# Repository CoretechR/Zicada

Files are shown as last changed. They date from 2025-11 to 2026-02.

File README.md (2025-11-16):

# Zicada - DIY Zigbee Multisensor

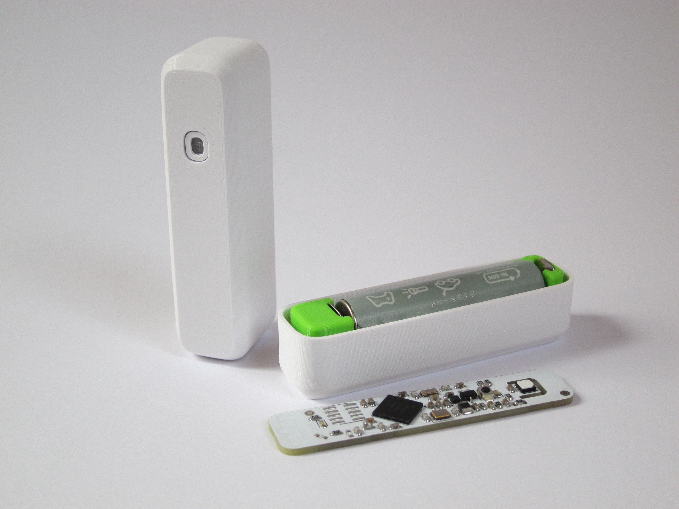
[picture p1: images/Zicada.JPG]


## Overview

Zicada is a DIY Zigbee sensor based on Nordic’s nRF52840 SoC. It combines a temperature and humidity sensor with a hall effect switch, making it suitable for both climate and door/window monitoring. Zicada is optimized for ultra-low power consumption, running at just 6µW in standby. This allows it to operate on a rechargeable AAA battery for 2 years or longer. It is fully compatible with Home Assistant (ZHA) and Zigbee2MQTT.

<div align="center">
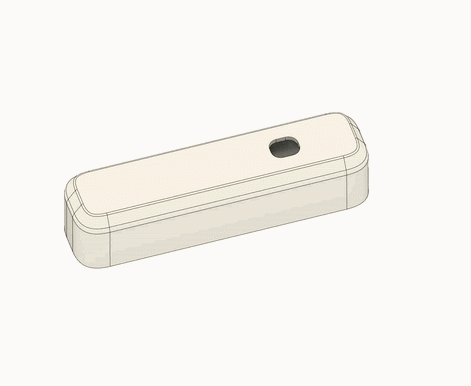
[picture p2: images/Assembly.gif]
  
</div>

### Features
* Temperature, humidity and contact sensing
* Zigbee 3.0 end device
* Compatible with Home Assistant (ZHA) and Zigbee2MQTT
* Ultra-low power consumption (6µW in Standby)
* 2+ years of battery life
* Supports AAA cells from 0.9V to 1.5V
* Small sized (62 x 15 mm) and fully 3D-printed case

### Setup Instructions

Follow these instructions to download and install the nRF Connect SDK version 2.6.0:
https://docs.nordicsemi.com/bundle/ncs-2.6.3/page/nrf/installation/install_ncs.html
Copy Zicada firmware folder into the directory ncs/projects.

When using the contact sensor with Zigbee2MQTT, copy the file "zicada_converter.js" to the directory data/external_converters/ of you Z2M install.

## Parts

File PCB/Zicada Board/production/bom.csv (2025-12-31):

Designator | Footprint | Quantity | Value | LCSC Part #
C10, C13, C14, C16, C19, C20, C21, C22, C24 | 0603 | 9 | 100nF | C1591
C11 | 0603 | 1 | 4.7uF | C1705
C12, C2 | 0603 | 2 | 1uF | C15849
C15, C17, C5, C6 | 0603 | 4 | 12pF | C107034
C18, C23 | 0603 | 2 | 10uF | C19702
C3 | 0603 | 1 | 820pF | C107057
C7 | 0603 | 1 | 0.5pF | C5137584
C8 | 0603 | 1 | 100pF | C14858
C9 | 0603 | 1 | 0.8pF | C519369
D1, D2 | 0603 | 2 | LED | C5875723
F1 | 0805 | 1 | 350mA | C207021
J2, J3 | MYOUNG MY-AAA-07 | 2 | Conn_01x01_Pin | C6937109
L1 | 0603 | 1 | 4.7nH | C1030
L2 | 1008 | 1 | 4.7uH | C280597
R1, R7 | 0603 | 2 | 0R | C116699
R2, R8 | 0603 | 2 | 330R | C105881
R4 | 0603 | 1 | 402R | C227889
R5, R6 | 0603 | 2 | 10K | C98220
SW1 | SW_SPST_B3U-1000P-B | 1 | SW_Push | C231329
U1 | Nordic_AQFN-73-1EP_7x7mm_P0.5mm | 1 | nRF52840 | C190794
U2 | Texas_PWSON-N6 | 1 | HDC2080 | C918141
U3 | SOT-23 | 1 | SM351LT | C80830
U4 | WSON-6_1.5x1.5mm_P0.5mm | 1 | TPS610981 | C470966
U5 | USON-6-1EP_2x2mm_P0.65mm_EP0.65x1.35mm | 1 | OPT3001 | C90462
Y1 | Crystal_SMD_Abracon_ABM8G-4Pin_3.2x2.5mm | 1 | 32MHz | C5552502
Y2 | Crystal_SMD_MicroCrystal_CC7V-T1A-2Pin_3.2x1.5mm | 1 | 32.768kHz | C32346

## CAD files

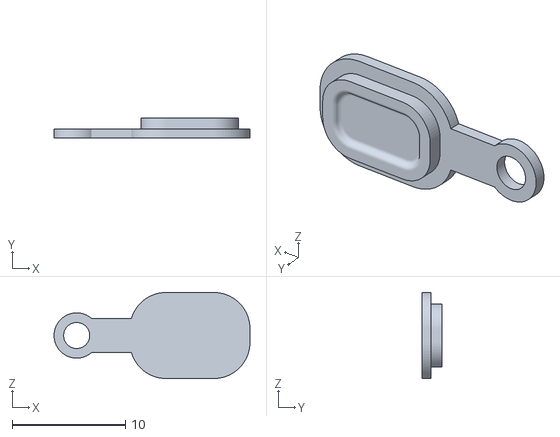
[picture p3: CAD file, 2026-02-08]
CAD/ButtonV2.stl
17.3 x 1.80 x 7.60

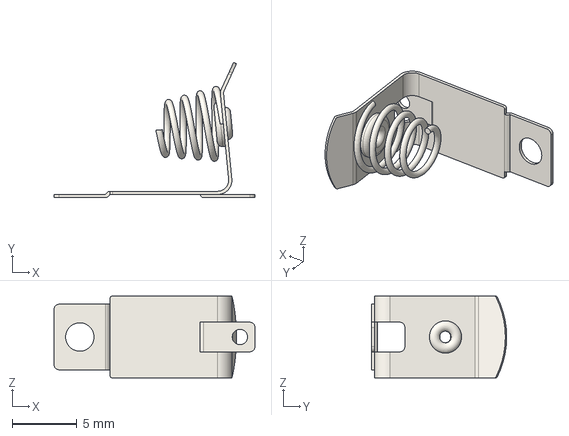
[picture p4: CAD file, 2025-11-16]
PCB/Zicada Board/project_libraries/3D-models/MY-AAA-22-J v3.step
15.6 x 10.5 x 6.35 mm

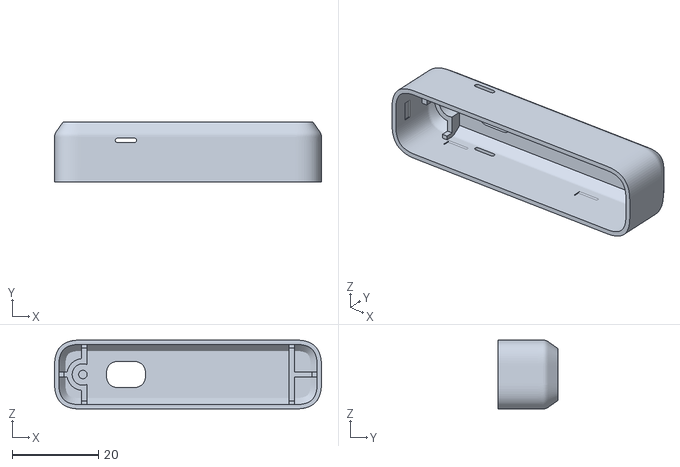
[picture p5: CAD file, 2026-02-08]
CAD/FrontV2.stl
62.0 x 14.0 x 16.0

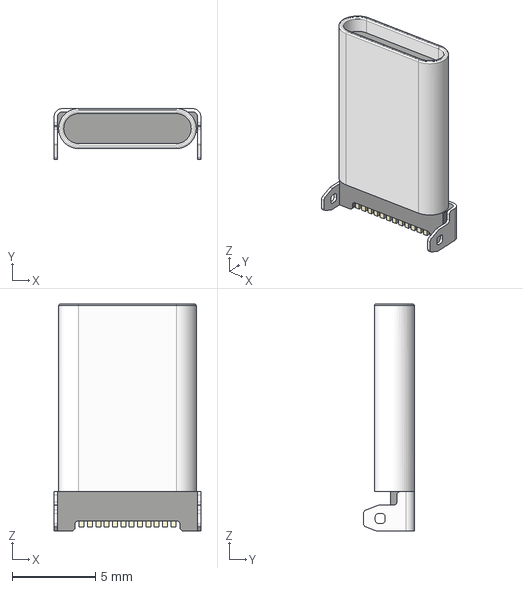
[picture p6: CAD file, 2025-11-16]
PCB/Zicada Board/project_libraries/3D-models/XKB Connection U261-121N-4BS2S v1.step
8.80 x 3.05 x 13.6 mm

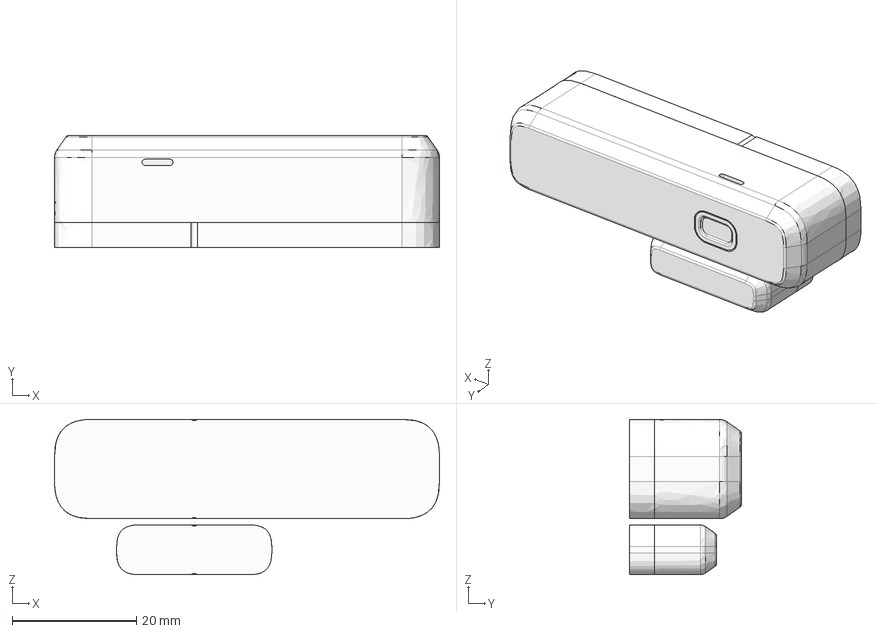
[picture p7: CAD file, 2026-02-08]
CAD/Zicada Rev2.step
62.0 x 18.0 x 25.0 mm
AAA_SIZE_BATTERY_CELL
C_0603_1608Metric x 22
L_1008_2520Metric
Crystal_SMD_Abracon_ABM8G-4Pin_3.2x2.5mm
LED_0603_1608Metric x 2
Fuse_0805_2012Metric
DFN-6-1EP_2x2mm_P0.65mm_EP1x1.6mm
R_0603_1608Metric x 7
SW_SPST_B3U-1000P-B
SOT-23
WSON-6_1.5x1.5mm_P0.5mm
L_0603_1608Metric
Texas_S-PWSON-N6
Nordic_AQFN-73-1EP_7x7mm_P0.5mm
Crystal_SMD_MicroCrystal_CC7V-T1A-2Pin_3.2x1.5mm
keystone-PN556 x 2
Zicada_pad
Zicada_PCB
Back
Button
Inlay
Magnet
MagBot
MagFront

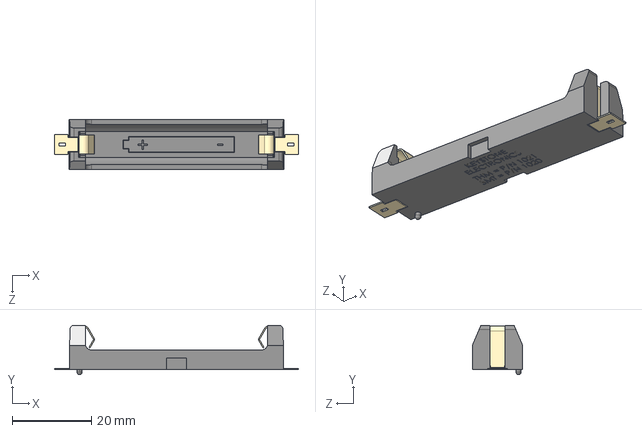
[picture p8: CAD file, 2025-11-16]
PCB/Zicada Board/project_libraries/3D-models/1020.step
61.5 x 12.4 x 12.7 mm

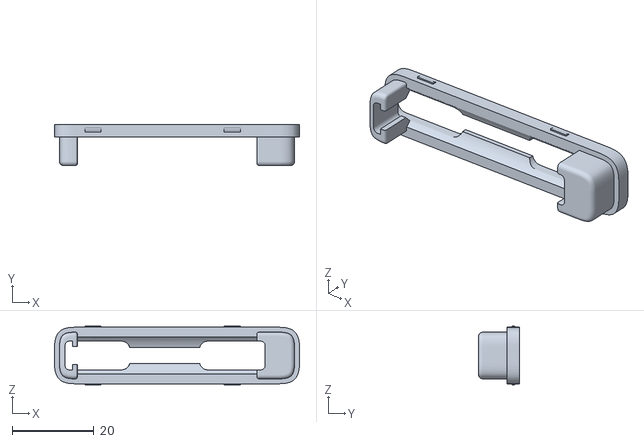
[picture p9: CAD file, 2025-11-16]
CAD/Inlay.stl
59.8 x 10.0 x 14.4

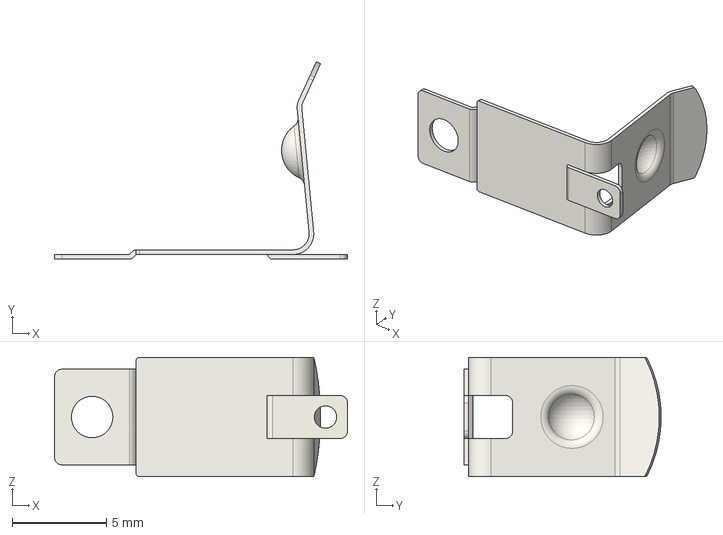
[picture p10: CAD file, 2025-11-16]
PCB/Zicada Board/project_libraries/3D-models/MY-AAA-07 v2.step
15.6 x 10.5 x 6.35 mm

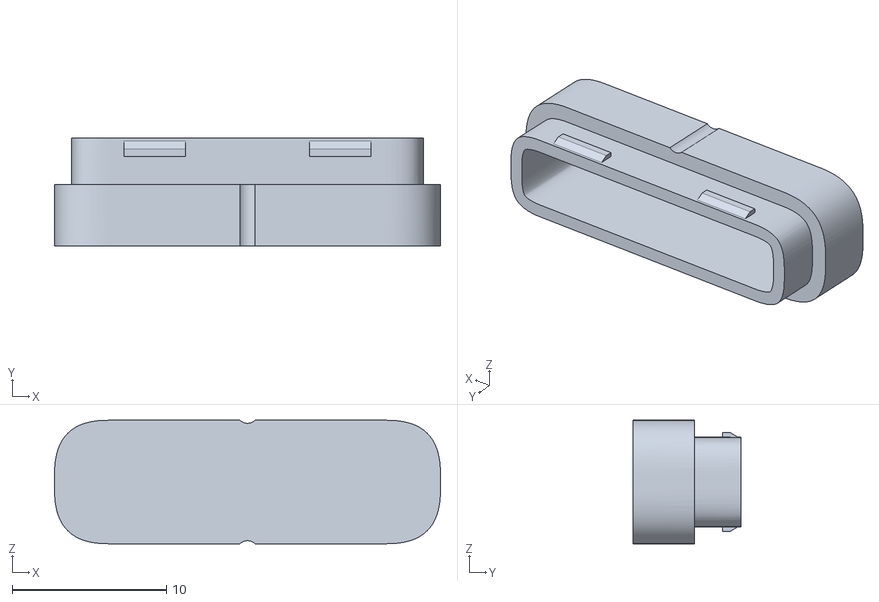
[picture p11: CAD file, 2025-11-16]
CAD/Mag Back.stl
25.0 x 7.00 x 8.00

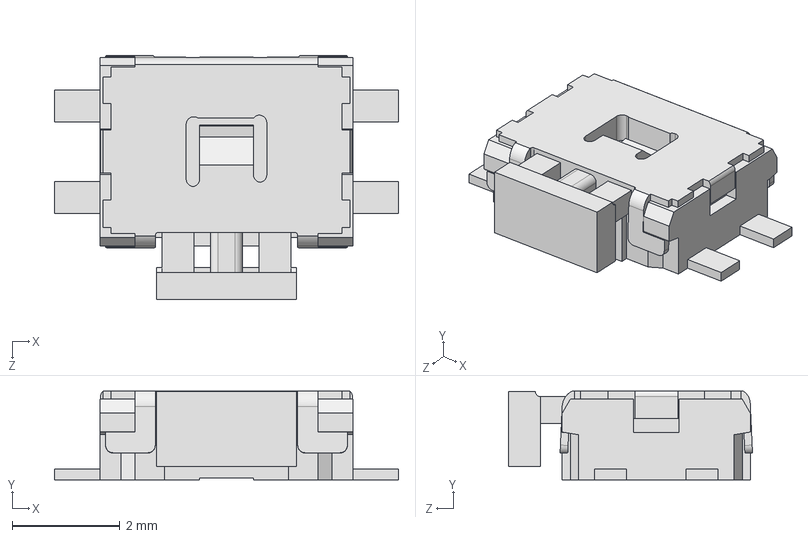
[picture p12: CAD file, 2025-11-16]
PCB/Zicada Board/project_libraries/3D-models/EVQPU-JA-02K.STEP
6.40 x 1.65 x 4.54 mm

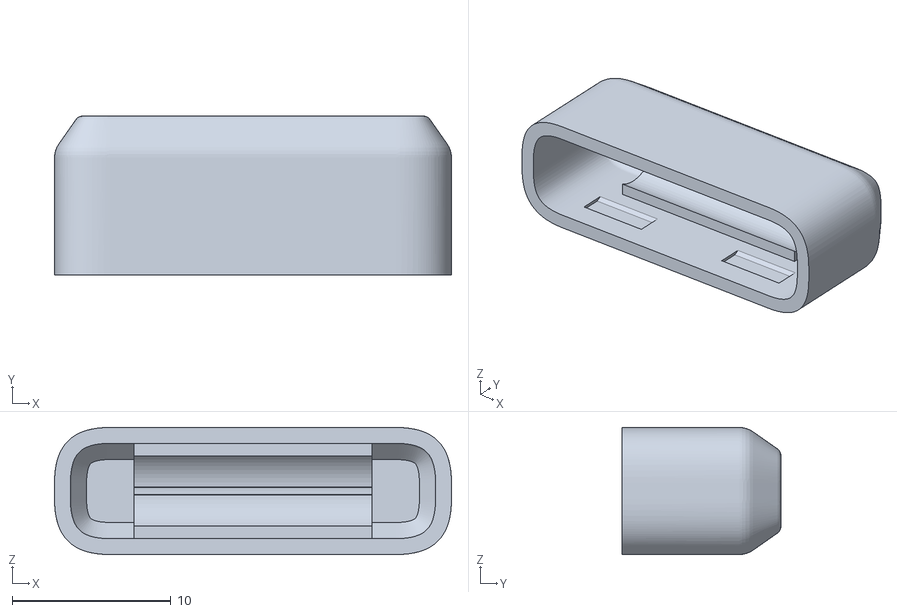
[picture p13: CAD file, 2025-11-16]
CAD/Mag Front.stl
25.0 x 10.0 x 8.00

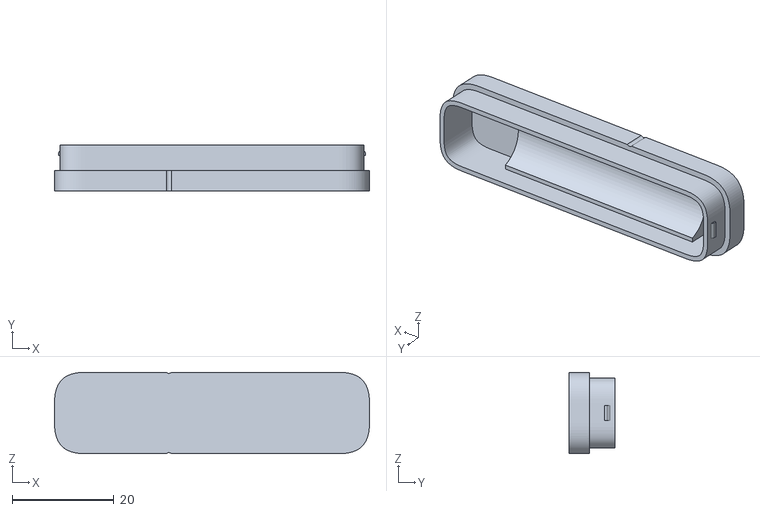
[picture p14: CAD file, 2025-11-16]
CAD/Back.stl
62.0 x 9.00 x 16.0

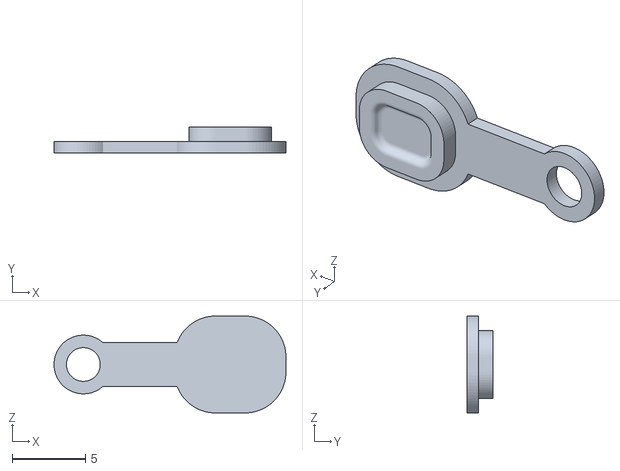
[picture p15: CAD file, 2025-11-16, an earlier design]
CAD/Button.stl
15.8 x 1.80 x 6.60

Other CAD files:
PCB/Zicada Board/project_libraries/3D-models/keystone-PN556.STEP
CAD/Front.stl

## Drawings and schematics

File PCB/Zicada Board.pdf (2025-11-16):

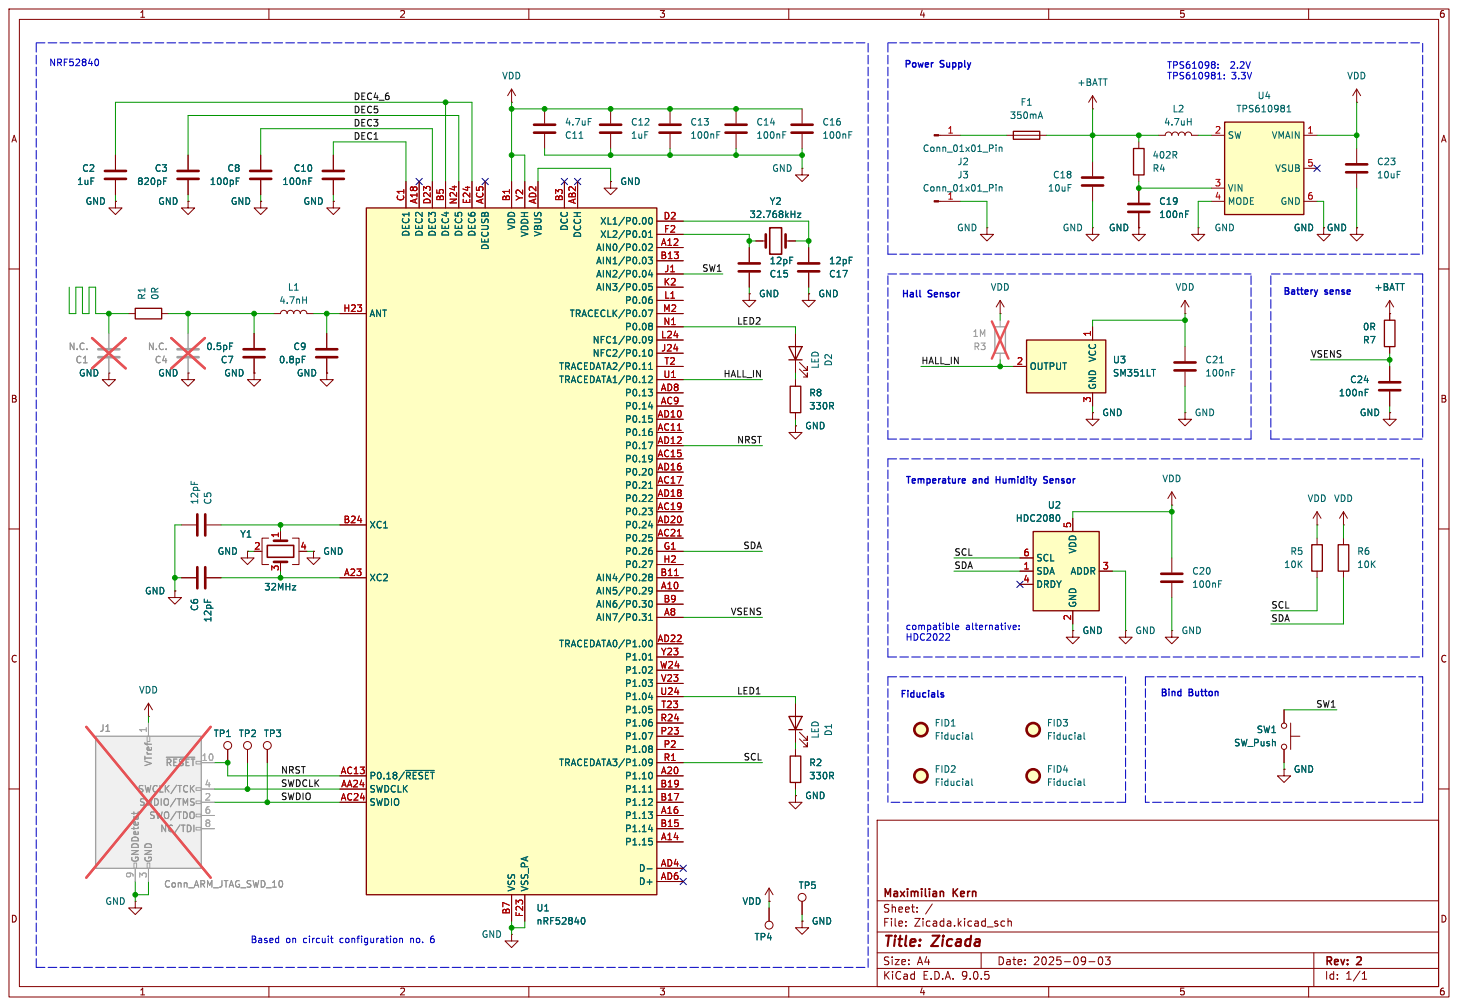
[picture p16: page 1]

2 SCL 6 SDA 1 DRDY 4 U2 HDC2080 GND GND GND

2 SCL 6 SDA 1 DRDY 4 GND GND

3 ~{RESET}10 SWCLK/TCK 4 SWDIO/TMS 2 SWO/TDO 6 NC/TDI 8

3 ~{RESET}10 SWCLK/TCK 4 SWDIO/TMS 2 SWO/TDO 6 NC/TDI 8 TP5GND

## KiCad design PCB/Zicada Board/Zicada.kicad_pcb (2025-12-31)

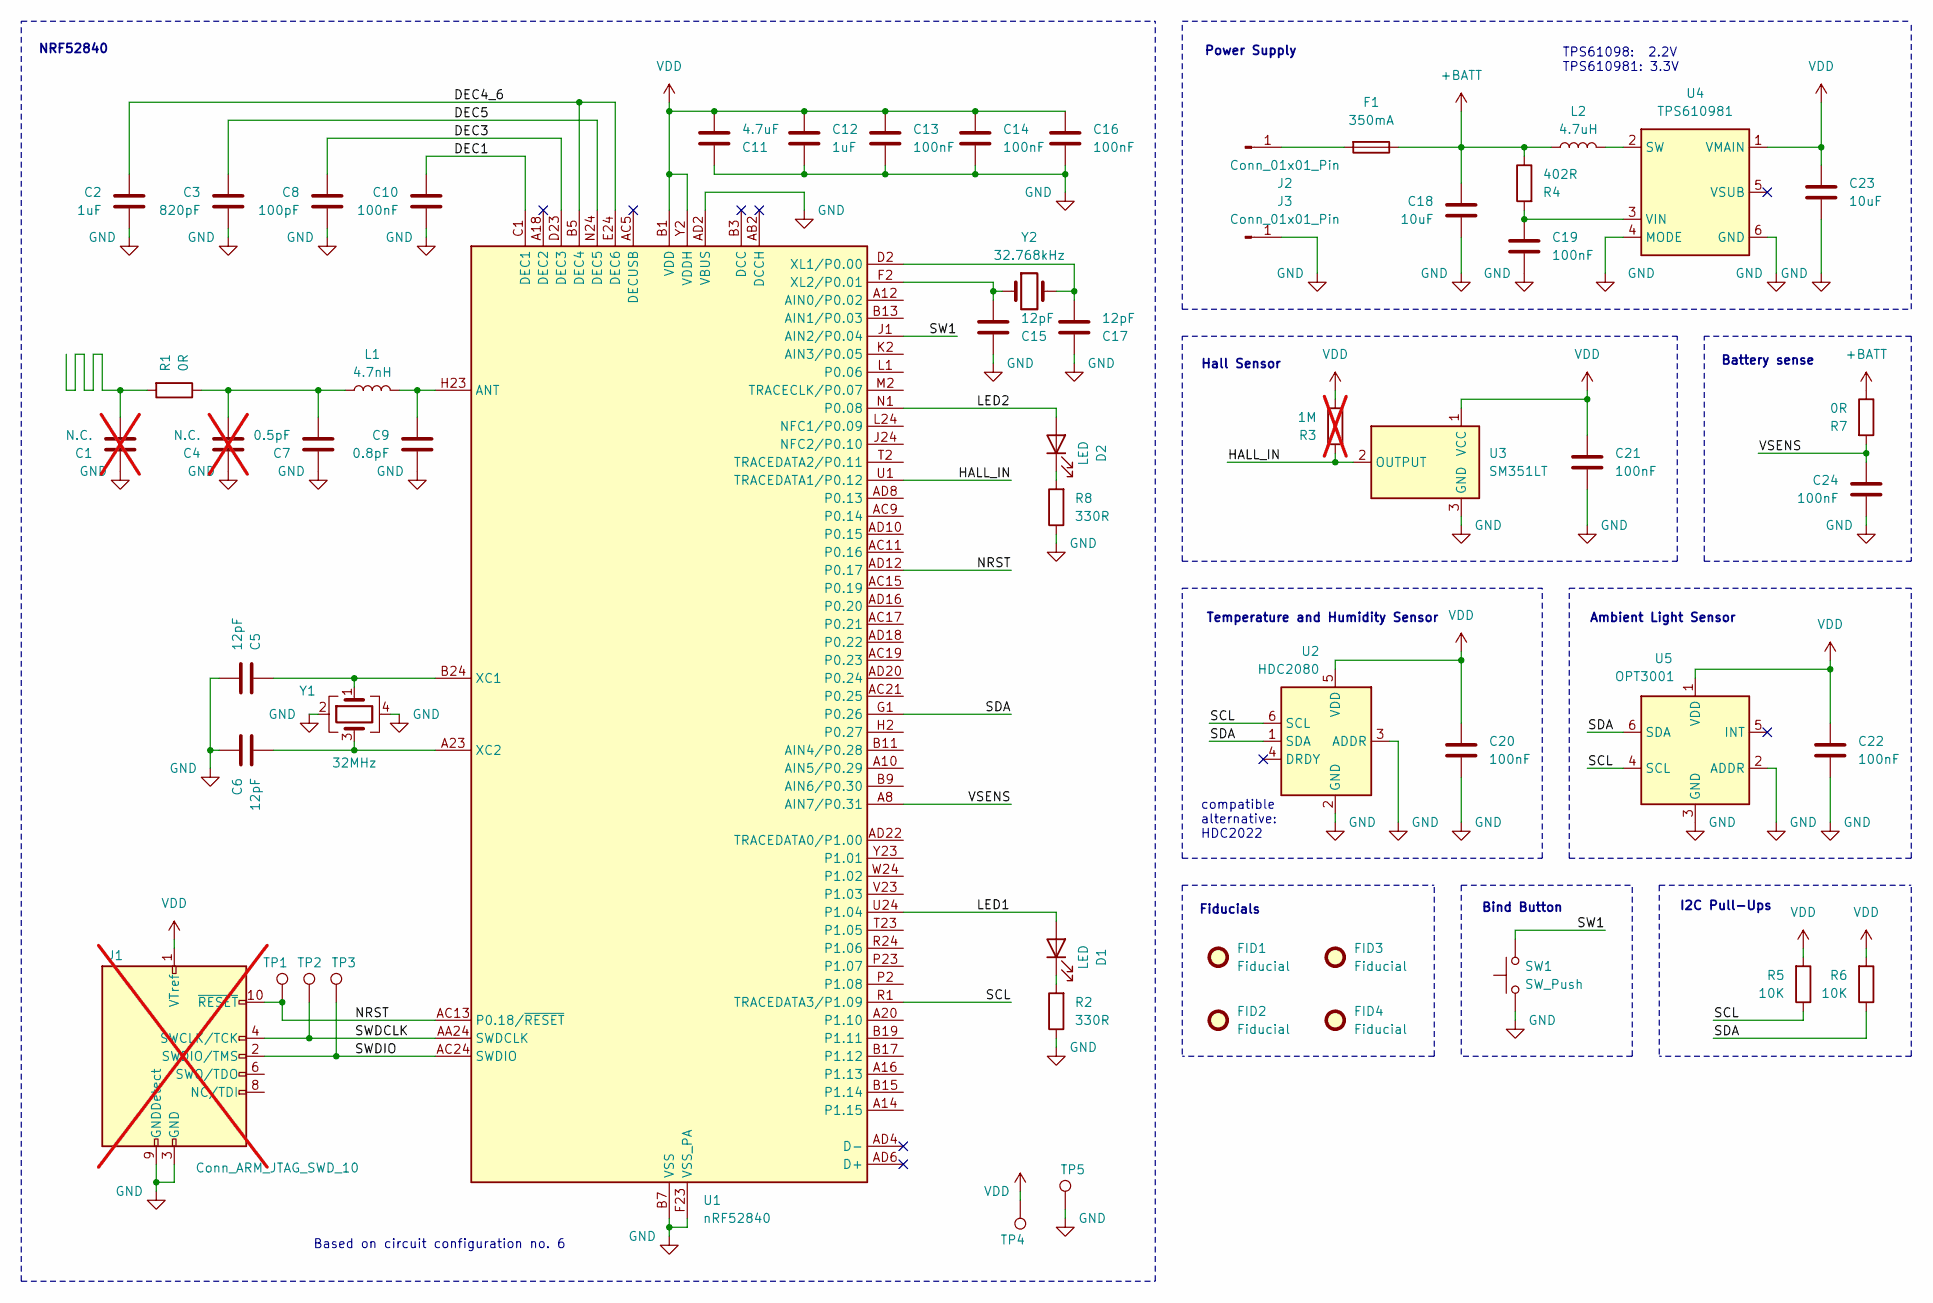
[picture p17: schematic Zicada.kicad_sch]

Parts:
C1, C4: N.C.; C_0603_1608Metric; not fitted
C2, C12: 1uF; C_0603_1608Metric; LCSC C15849
C3: 820pF; C_0603_1608Metric; LCSC C107057
C5, C6, C15, C17: 12pF; C_0603_1608Metric; LCSC C107034
C7: 0.5pF; C_0603_1608Metric; LCSC C5137584
C8: 100pF; C_0603_1608Metric; LCSC C14858
C9: 0.8pF; C_0603_1608Metric; LCSC C519369
C10, C13, C14, C16, C19, C20, C21, C22, C24: 100nF; C_0603_1608Metric; LCSC C1591
C11: 4.7uF; C_0603_1608Metric; LCSC C1705
C18, C23: 10uF; C_0603_1608Metric; LCSC C19702
D1, D2: LED; LED_0603_1608Metric; LCSC C5875723
F1: 350mA; Fuse_0805_2012Metric; LCSC C207021
FID1, FID2, FID3, FID4: Fiducial; Fiducial_1mm_Mask2mm
J1: Conn_ARM_JTAG_SWD_10; PinHeader_2x05_P1.27mm_Vertical_SMD; not fitted
J2, J3: Conn_01x01_Pin; MYOUNG MY-AAA-07; LCSC C6937109
L1: 4.7nH; L_0603_1608Metric; LCSC C1030
L2: 4.7uH; L_1008_2520Metric; LCSC C280597
R1, R7: 0R; R_0603_1608Metric; LCSC C116699
R2, R8: 330R; R_0603_1608Metric; LCSC C105881
R3: 1M; R_0603_1608Metric; LCSC C105578; not fitted
R4: 402R; R_0603_1608Metric; LCSC C227889
R5, R6: 10K; R_0603_1608Metric; LCSC C98220
SW1: SW_Push; SW_SPST_B3U-1000P-B; LCSC C231329
TP1, TP2, TP3, TP4, TP5: TestPoint; TestPoint_Pad_D1.5mm
U1: nRF52840; Nordic_AQFN-73-1EP_7x7mm_P0.5mm; LCSC C190794
U2: HDC2080; Texas_PWSON-N6; LCSC C918141
U3: SM351LT; SOT-23; LCSC C80830
U4: TPS610981; WSON-6_1.5x1.5mm_P0.5mm; LCSC C470966
U5: OPT3001; USON-6-1EP_2x2mm_P0.65mm_EP0.65x1.35mm; LCSC C90462
Y1: 32MHz; Crystal_SMD_Abracon_ABM8G-4Pin_3.2x2.5mm; LCSC C5552502
Y2: 32.768kHz; Crystal_SMD_MicroCrystal_CC7V-T1A-2Pin_3.2x1.5mm; LCSC C32346

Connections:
+BATT: C18.1, F1.1, L2.1, R4.1, R7.1
/DEC1: C10.1, U1.C1 (DEC1)
/DEC3: C8.1, U1.D23 (DEC3)
/DEC4_6: C2.1, U1.B5 (DEC4), U1.E24 (DEC6)
/DEC5: C3.1, U1.N24 (DEC5)
/HALL_IN: R3.2, U1.U1 (TRACEDATA1/P0.12), U3.2 (OUTPUT)
/LED1: D1.2 (A), U1.U24 (P1.04)
/LED2: D2.2 (A), U1.N1 (P0.08)
/NRST: J1.10 (~RESET), TP1.1, U1.AC13 (P0.18/~RESET), U1.AD12 (P0.17)
/SCL: R5.1, U1.R1 (TRACEDATA3/P1.09), U2.6 (SCL), U5.4 (SCL)
/SDA: R6.1, U1.G1 (P0.26), U2.1 (SDA), U5.6 (SDA)
/SW1: SW1.2, U1.J1 (AIN2/P0.04)
/SWDCLK: J1.4 (SWCLK/TCK), TP2.1, U1.AA24 (SWDCLK)
/SWDIO: J1.2 (SWDIO/TMS), TP3.1, U1.AC24 (SWDIO)
/VSENS: C24.1, R7.2, U1.A8 (AIN7/P0.31)
GND: C1.1, C2.2, C3.2, C4.1, C5.2, C6.1, C7.1, C8.2, C9.2, C10.2, C11.1, C12.2, C13.2, C14.2, C15.1, C16.2, C17.1, C18.2, C19.2, C20.2, C21.2, C22.2, C23.2, C24.2, J1.3 (GND), J1.5 (GND), J1.9 (GNDDetect), J3.1, R2.1, R8.1, SW1.1, TP5.1, U1.AD2 (VBUS), U1.B7 (VSS), U1.EP (VSS), U1.F23 (VSS_PA), U2.2 (GND), U2.3 (ADDR), U3.3 (GND), U4.4 (MODE), U4.6 (GND), U5.2 (ADDR), U5.3 (GND), Y1.2, Y1.4
unnamed: C1.2, R1.2
unnamed: C4.2, C7.2, L1.1, R1.1
unnamed: D1.1 (K), R2.2
unnamed: D2.1 (K), R8.2
unnamed: F1.2, J2.1
unnamed: C9.1, L1.2, U1.H23 (ANT)
unnamed: C5.1, U1.B24 (XC1), Y1.1
unnamed: C6.2, U1.A23 (XC2), Y1.3
unnamed: C17.2, U1.D2 (XL1/P0.00), Y2.2
unnamed: C15.2, U1.F2 (XL2/P0.01), Y2.1
unnamed: L2.2, U4.2 (SW)
unnamed: C19.1, R4.2, U4.3 (VIN)
VDD: C11.2, C12.1, C13.1, C14.1, C16.1, C20.1, C21.1, C22.1, C23.1, J1.1 (VTref), R3.1, R5.2, R6.2, TP4.1, U1.A22 (VDD), U1.AD14 (VDD), U1.AD23 (VDD), U1.B1 (VDD), U1.W1 (VDD), U1.Y2 (VDDH), U2.5 (VDD), U3.1 (VCC), U4.1 (VMAIN), U5.1 (VDD)

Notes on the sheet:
NRF52840
Ambient Light Sensor
Temperature and Humidity Sensor
Based on circuit configuration no. 6
compatible alternative: HDC2022
Bind Button
Power Supply
TPS61098: 2.2V TPS610981: 3.3V
Fiducials
Battery sense
I2C Pull-Ups
Hall Sensor

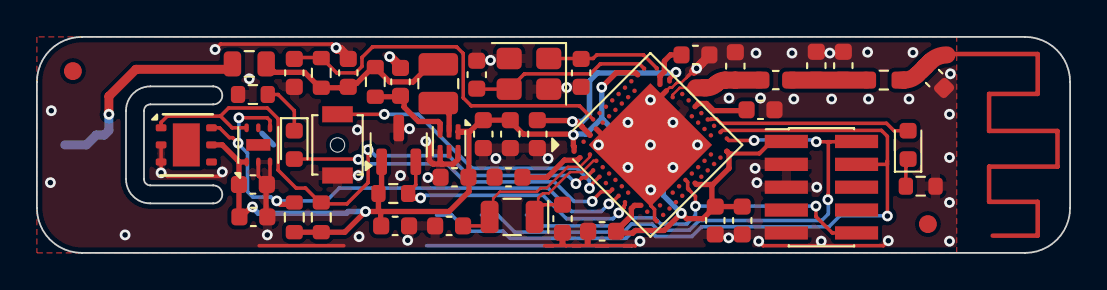
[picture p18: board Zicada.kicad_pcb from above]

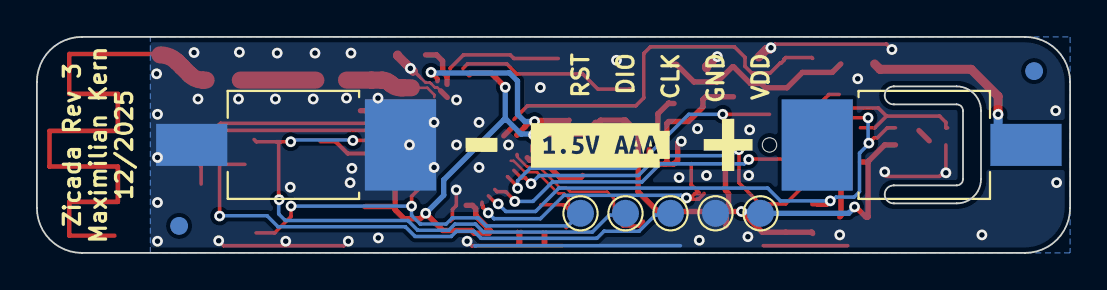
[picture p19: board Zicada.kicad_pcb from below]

Board: 2 copper layers, 57.4 x 12.0 mm, 60 parts (12 on the bottom side), 29 nets.

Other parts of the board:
kibuzzard-6898F1CE: G***; kibuzzard-6898F1CE
kibuzzard-6898F6DD: G***; kibuzzard-6898F6DD
kibuzzard-6898F105: G***; kibuzzard-6898F105

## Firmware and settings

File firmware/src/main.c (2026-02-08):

// 2026 Maximilian Kern
// Based on Glen Akins' homebrew Zigbee Devices: https://github.com/bikerglen/homebrew_zigbee_devices

//---------------------------------------------------------------------------------------------
// includes
//

#include <zephyr/kernel.h>
#include <zephyr/device.h>
#include <zephyr/logging/log.h>
#include <zephyr/drivers/gpio.h>
#include <zephyr/drivers/sensor.h>
#include <dk_buttons_and_leds.h>
#include <ram_pwrdn.h>
#include <drivers/include/nrfx_saadc.h>
#include <math.h>
#include <zephyr/drivers/i2c.h>

#include <zboss_api.h>
#include <zboss_api_addons.h>
#include <zb_zcl_reporting.h>
#include <zigbee/zigbee_app_utils.h>
#include <zigbee/zigbee_error_handler.h>
#include <zb_nrf_platform.h>
#include <zb_zcl_rel_humidity_measurement.h>
#include "zb_mem_config_custom.h"
#include "zb_zicada.h"

//---------------------------------------------------------------------------------------------
// defines
//

// Uncomment to enable reports on release in addition to the standard reports on press
#define ENABLE_BUTTON_RELEASE_REPORTS

// Basic cluster attributes initial values. For more information, see section 3.2.2.2 of the ZCL specification.
#define ZICADA_INIT_BASIC_APP_VERSION		01									// Version of the application software (1 byte).
#define ZICADA_INIT_BASIC_STACK_VERSION		01									// Version of the implementation of the Zigbee stack (1 byte).
#define ZICADA_INIT_BASIC_HW_VERSION		01									// Version of the hardware of the device (1 byte).
#define ZICADA_INIT_BASIC_MANUF_NAME		"kernm.de"							// Manufacturer name (32 bytes).
#define ZICADA_INIT_BASIC_MODEL_ID			"Zicada"							// Model number assigned by the manufacturer (32-bytes long string).
#define ZICADA_INIT_BASIC_DATE_CODE			"20260201"							// Date provided by the manufacturer of the device in ISO 8601 format (YYYYMMDD), for the first 8 bytes. The remaining 8 bytes are manufacturer-specific.
#define ZICADA_INIT_BASIC_POWER_SOURCE		ZB_ZCL_BASIC_POWER_SOURCE_BATTERY	// Type of power source or sources available for the device. For possible values, see section 3.2.2.2.8 of the ZCL specification.
#define ZICADA_INIT_BASIC_LOCATION_DESC		"Home"								// Description of the physical location of the device (16 bytes). You can modify it during the commisioning process.
#define ZICADA_INIT_BASIC_PH_ENV			ZB_ZCL_BASIC_ENV_UNSPECIFIED		// Description of the type of physical environment. For possible values, see section 3.2.2.2.10 of the ZCL specification.

// source endpoint for our device
#define SOURCE_ENDPOINT            1

// destination short address and endpoint (always endpoint 1 on the coordinator)
#define DEST_SHORT_ADDR            0x0000
#define DEST_ENDPOINT              1

// Do not erase NVRAM to save the network parameters after device reboot or
// power-off. NOTE: If this option is set to ZB_TRUE then do full device erase
// for all network devices before running other samples.
#define ERASE_PERSISTENT_CONFIG    ZB_FALSE

// LED
#define ZIGBEE_NETWORK_STATE_LED   0      // on: disconnected, blinking: identify, off: normal operation

// Button
#define BUTTON_0				BIT(0) // short press: identify, long press: factory reset

// Hall sensor
static const struct gpio_dt_spec hall_sensor = GPIO_DT_SPEC_GET(DT_NODELABEL(hall_sensor_input), gpios);

// Temperature and humidity sensor
const struct device *const hdc20 = DEVICE_DT_GET_ONE(ti_hdc2080);

// Light sensor
const struct device *const opt30 = DEVICE_DT_GET_ONE(ti_opt3001);

// read and report battery voltage after an initial delay after joining the network 
// then read and report battery voltage after the specified period elapses.
#define BATTERY_CHECK_PERIOD_MSEC (1000 * 60 * 60 * 6) // 6 hours
#define BATTERY_CHECK_INITIAL_DELAY_MSEC (1000 * 60 * 1) // 1 minute

#define TEMP_HUMIDITY_CHECK_PERIOD_MSEC (1000 * 60 * 5) // 5 minutes
#define TEMP_HUMIDITY_CHECK_INITIAL_DELAY_MSEC (1000 * 10) // 10 seconds

#define REJOIN_ATTEMPT_PERIOD_MSEC (1000 * 60 * 5) // 5 minutes
#define REJOIN_ATTEMPT_INITIAL_DELAY_MSEC (1000 * 30) // 30 seconds

#define CONTACT_LED_INDICATION_DURATION_MSEC 500  // 500ms LED flash

// Zigbee Cluster Library 4.4.2.2.1.1: MeasuredValue = 100x temperature in degrees Celsius */
#define ZCL_TEMPERATURE_MEASUREMENT_MEASURED_VALUE_MULTIPLIER 100
// Zigbee Cluster Library 4.7.2.1.1: MeasuredValue = 100x water content in % */
#define ZCL_HUMIDITY_MEASUREMENT_MEASURED_VALUE_MULTIPLIER 100

struct opt3001_config_header {
    struct i2c_dt_spec i2c;
};

// OPT3001 register definitions
#define OPT3001_REG_CONFIG   0x01
#define OPT3001_SHUTDOWN     0x0010  // Mode=00 (Shutdown), Range=Auto
#define OPT3001_CONTINUOUS   0xCE10  // Mode=11 (Continuous), Range=Auto, 100ms 

//---------------------------------------------------------------------------------------------
// typedefs
//


// attribute storage for battery power config
struct zb_zcl_power_attrs {
    zb_uint8_t voltage; // Attribute 3.3.2.2.3.1
    zb_uint8_t size; // Attribute 3.3.2.2.4.2
    zb_uint8_t quantity; // Attribute 3.3.2.2.4.4
    zb_uint8_t percent_remaining; // Attribute 3.3.2.2.3.1
};

typedef struct zb_zcl_power_attrs zb_zcl_power_attrs_t;

struct zb_zcl_humidity_measurement_attrs_t
{
	zb_int16_t measure_value;
	zb_int16_t min_measure_value;
	zb_int16_t max_measure_value;
};

struct zb_zcl_illuminance_measurement_attrs_t
{
	zb_int16_t measure_value;
	zb_int16_t min_measure_value;
	zb_int16_t max_measure_value;
};

// attribute storage for our device
struct zb_device_ctx {
	zb_zcl_basic_attrs_ext_t basic_attr;
	zb_zcl_identify_attrs_t identify_attr;
	zb_zcl_temp_measurement_attrs_t temp_attrs;
	struct zb_zcl_humidity_measurement_attrs_t humidity_attrs;
	struct zb_zcl_illuminance_measurement_attrs_t illuminance_attrs;
	zb_zcl_on_off_attrs_t on_off_attrs;
	zb_zcl_power_attrs_t power_attr;
};

// storage for the destination short address and endpoint number
struct dest_context {
	zb_uint8_t endpoint;
	zb_uint16_t short_addr;
};

// coin cell voltage-capacity pairs
typedef struct {
  uint16_t      voltage;
  uint8_t       capacity;
} voltage_capacity_pair_t;

// Add an attribute storage struct for On/Off server
struct zb_zcl_on_off_attrs {
    zb_bool_t on_off;
};

//---------------------------------------------------------------------------------------------
// Prototypes
//

// used to display reporting info structures if needed
zb_zcl_reporting_info_t *zb_zcl_get_reporting_info(zb_uint8_t slot_number);

void zboss_signal_handler (zb_bufid_t bufid);
static void configure_gpio (void);
static void button_handler (uint32_t button_state, uint32_t has_changed);
static void contact_send_on_off (zb_bufid_t bufid, zb_uint16_t cmd_id);
static void start_identifying (zb_bufid_t bufid);
static void identify_cb (zb_bufid_t bufid);
static void toggle_identify_led (zb_bufid_t bufid);
static void app_clusters_attr_init (void);
static void check_battery_level(zb_bufid_t bufid);
static uint8_t NiMH_CalculateLevel (uint16_t voltage);
static void configure_attribute_reporting (void);
static void check_hall_sensor_and_send_command(zb_bufid_t bufid);
static void hall_sensor_interrupt_callback(const struct device *dev, struct gpio_callback *cb, uint32_t pins);
static void attempt_rejoin(zb_bufid_t bufid);
static void turn_off_led(zb_bufid_t bufid);

//---------------------------------------------------------------------------------------------
// Globals
//

LOG_MODULE_REGISTER (app, LOG_LEVEL_INF);

// Stores all cluster-related attributes
static struct zb_device_ctx dev_ctx;

// storage for the destination short address and endpoint number
static struct dest_context dest_ctx;

// Global variable to track current hall sensor state
static bool current_hall_state = false;

// Attributes setup
ZB_ZCL_DECLARE_BASIC_ATTRIB_LIST_EXT(
	basic_server_attr_list, 
	&dev_ctx.basic_attr.zcl_version,
	&dev_ctx.basic_attr.app_version,
	&dev_ctx.basic_attr.stack_version,
	&dev_ctx.basic_attr.hw_version, 
	dev_ctx.basic_attr.mf_name,
	dev_ctx.basic_attr.model_id, 
	dev_ctx.basic_attr.date_code,
	&dev_ctx.basic_attr.power_source,
	dev_ctx.basic_attr.location_id, 
	&dev_ctx.basic_attr.ph_env,
	dev_ctx.basic_attr.sw_ver
);

// Declare attribute list for Identify cluster (client).
ZB_ZCL_DECLARE_IDENTIFY_CLIENT_ATTRIB_LIST(
	identify_client_attr_list
);

// Declare attribute list for Identify cluster (server).
ZB_ZCL_DECLARE_IDENTIFY_SERVER_ATTRIB_LIST(
	identify_server_attr_list,
	&dev_ctx.identify_attr.identify_time
);

// Declare attribute list for temperature measurement (server).
ZB_ZCL_DECLARE_TEMP_MEASUREMENT_ATTRIB_LIST(
	temperature_measurement_attr_list,
	&dev_ctx.temp_attrs.measure_value,
	&dev_ctx.temp_attrs.min_measure_value,
	&dev_ctx.temp_attrs.max_measure_value,
	&dev_ctx.temp_attrs.tolerance
);

// Declare attribute list for humidity measurement (server).
ZB_ZCL_DECLARE_REL_HUMIDITY_MEASUREMENT_ATTRIB_LIST(
	humidity_measurement_attr_list,
	&dev_ctx.humidity_attrs.measure_value,
	&dev_ctx.humidity_attrs.min_measure_value,
	&dev_ctx.humidity_attrs.max_measure_value
);

// Declare attribute list for illuminance measurement (server).
ZB_ZCL_DECLARE_ILLUMINANCE_MEASUREMENT_ATTRIB_LIST(
	illuminance_measurement_attr_list,
	&dev_ctx.illuminance_attrs.measure_value,
	&dev_ctx.illuminance_attrs.min_measure_value,
	&dev_ctx.illuminance_attrs.max_measure_value
);

// Declare attribute list for On/Off cluster (client).
ZB_ZCL_DECLARE_ON_OFF_CLIENT_ATTRIB_LIST(
	on_off_client_attr_list
);

// Declare attribute list for power configuration cluster (server).
// https://devzone.nordicsemi.com/f/nordic-q-a/85315/zboss-declare-power-config-attribute-list-for-battery-bat_num
#define bat_num
ZB_ZCL_DECLARE_POWER_CONFIG_BATTERY_ATTRIB_LIST_EXT(
    power_config_server_attr_list,
    &dev_ctx.power_attr.voltage,
    /*battery_size=*/&dev_ctx.power_attr.size,
    /*battery_quantity=*/&dev_ctx.power_attr.quantity,
    /*battery_rated_voltage=*/NULL,
    /*battery_alarm_mask=*/NULL,
    /*battery_voltage_min_threshold=*/NULL,
    /*battery_percentage_remaining=*/&dev_ctx.power_attr.percent_remaining,
    /*battery_voltage_threshold1=*/NULL,
    /*battery_voltage_threshold2=*/NULL,
    /*battery_voltage_threshold3=*/NULL,
    /*battery_percentage_min_threshold=*/NULL,
    /*battery_percentage_threshold1=*/NULL,
    /*battery_percentage_threshold2=*/NULL,
    /*battery_percentage_threshold3=*/NULL,
    /*battery_alarm_state=*/NULL);

// Cluster setup
ZB_DECLARE_ZICADA_CLUSTER_LIST(
	zicada_clusters, 
	basic_server_attr_list,
	identify_client_attr_list, 
	identify_server_attr_list,
	temperature_measurement_attr_list,
	humidity_measurement_attr_list,
	illuminance_measurement_attr_list,
	on_off_client_attr_list,
	power_config_server_attr_list
);

// Declare endpoint
ZB_DECLARE_ZICADA_EP(
	zicada_ep, 
	SOURCE_ENDPOINT,
	zicada_clusters
);

// Declare application's device context (list of registered endpoints) for Zicada sensor.
ZBOSS_DECLARE_DEVICE_CTX_1_EP(
	zicada_ctx, 
	zicada_ep
);

// This allows for the initial values to be set correctly
double measured_temperature = 0;
double measured_humidity = 0;
double measured_illuminance = 0;

// Voltage - Capacity pair table from thunderboard react
// Algorithm assumes the values are arranged in a descending order.
// The values in the table are base on the discharge curve from lygte-info.dk:
// https://lygte-info.dk/review/batteries2012/Ikea%20Ladda%20AA%202450mAh%20%28White%29%20UK.html
// Table modified for zigbee half percent steps.
static voltage_capacity_pair_t vcPairs[] =
{ { 1450, 100 }, { 1350, 92 }, { 1300, 78 }, { 1250, 24 }, { 1220, 13 },
  { 1160, 5 }, { 1100, 2 }, { 900, 0 } };

// change the opt3001 light sensor's mode by writing to its config register directly
// This is a workaround because the driver can't be used to update the config register
static int opt3001_write_mode(const struct device *dev, uint16_t mode_val) {
    const struct opt3001_config_header *cfg = (const struct opt3001_config_header *)dev->config;
    if (!device_is_ready(cfg->i2c.bus)) return -ENODEV;
    
    uint8_t tx[3] = { OPT3001_REG_CONFIG, mode_val >> 8, mode_val & 0xFF };
    return i2c_write_dt(&cfg->i2c, tx, sizeof(tx));
}

//---------------------------------------------------------------------------------------------
// main
//


int main (void)
{
	LOG_INF ("Starting Zicada sensor");

	// initialize
	configure_gpio ();

	// init HDC20xx
	if (!device_is_ready(hdc20)) {
		LOG_ERR("HDC20xx: device not ready");
		return 0;
	} else LOG_INF("HDC20xx: device ready");

	// init OPT300x
	if (!device_is_ready(opt30)) {
		LOG_ERR("OPT300x: device not ready");
		return 0;
	} else LOG_INF("OPT300x: device ready");
	
	// get initial temperature and humidity
	struct sensor_value temp, humidity;
	sensor_sample_fetch(hdc20);
	sensor_channel_get(hdc20, SENSOR_CHAN_AMBIENT_TEMP, &temp);
	sensor_channel_get(hdc20, SENSOR_CHAN_HUMIDITY, &humidity);
	measured_temperature = sensor_value_to_double(&temp);
	measured_humidity = sensor_value_to_double(&humidity);
	LOG_INF("Temp = %f C, RH = %f", measured_temperature, measured_humidity);
	
	// get initial ambient brightness
	struct sensor_value brightness;
	sensor_sample_fetch(opt30);
	sensor_channel_get(opt30, SENSOR_CHAN_LIGHT, &brightness);
	sensor_channel_get(opt30, SENSOR_CHAN_LIGHT, &brightness);
	measured_illuminance = sensor_value_to_double(&brightness);
	LOG_INF("Brightness = %f", measured_illuminance);
	// force light sensor into shutdown mode
	opt3001_write_mode(opt30, OPT3001_SHUTDOWN);

	// init Zigbee
	register_factory_reset_button (BUTTON_0);
	zigbee_erase_persistent_storage (ERASE_PERSISTENT_CONFIG);
	zb_set_ed_timeout (ED_AGING_TIMEOUT_64MIN);
    zb_set_keepalive_timeout (ZB_MILLISECONDS_TO_BEACON_INTERVAL(3600*1000));

	// send things to endpoint 1 on the coordinator
	dest_ctx.short_addr = DEST_SHORT_ADDR;
	dest_ctx.endpoint = DEST_ENDPOINT;

	// configure for lowest power
	zigbee_configure_sleepy_behavior (true);
	power_down_unused_ram ();

	// register switch device context (endpoints)
	ZB_AF_REGISTER_DEVICE_CTX (&zicada_ctx);

	// initialize application clusters
	app_clusters_attr_init ();

	// register handlers to identify notifications
	ZB_AF_SET_IDENTIFY_NOTIFICATION_HANDLER(SOURCE_ENDPOINT, identify_cb);

	// start Zigbee default thread
	zigbee_enable ();

	LOG_INF ("Zicada sensor started");

	// suspend main thread
	while (1) {
		k_sleep (K_FOREVER);
	}
}

//---------------------------------------------------------------------------------------------
// Temperature and humidity check routine
//

static void check_temp_humidity(zb_bufid_t bufid){

	ZVUNUSED(bufid);

	sensor_sample_fetch(hdc20);

	int16_t temperature_attribute = 0;

	struct sensor_value temp;
	sensor_channel_get(hdc20, SENSOR_CHAN_AMBIENT_TEMP, &temp);
	measured_temperature = sensor_value_to_double(&temp);
	
	// Convert measured value to attribute value, as specified in ZCL
	temperature_attribute = (int16_t)(measured_temperature * ZCL_TEMPERATURE_MEASUREMENT_MEASURED_VALUE_MULTIPLIER);
	//LOG_INF("Attribute T:%10d", temperature_attribute);

	// Set ZCL attribute
	zb_zcl_status_t status = zb_zcl_set_attr_val(
		SOURCE_ENDPOINT,							// 1
		ZB_ZCL_CLUSTER_ID_TEMP_MEASUREMENT,			// 0x0402
		ZB_ZCL_CLUSTER_SERVER_ROLE,					// 1
		ZB_ZCL_ATTR_TEMP_MEASUREMENT_VALUE_ID,
		(zb_uint8_t *)&temperature_attribute,
		ZB_FALSE
	);

	if (status) {
		LOG_ERR("Failed to set ZCL attribute: %d", status);
	} else{
		LOG_INF("Temperature attribute update: %.2f C", measured_temperature);
		//if(measured_temperature++ >= 50) measured_temperature = 0; // increment temperature for testing
	}

	int16_t humidity_attribute = 0;
	
	struct sensor_value humidity;
	sensor_channel_get(hdc20, SENSOR_CHAN_HUMIDITY, &humidity);
	measured_humidity = sensor_value_to_double(&humidity);
	
	// Convert measured value to attribute value, as specified in ZCL
	humidity_attribute = (int16_t)(measured_humidity * ZCL_HUMIDITY_MEASUREMENT_MEASURED_VALUE_MULTIPLIER);
	//LOG_INF("Attribute H:%10d", humidity_attribute);

	// Set ZCL attribute
	status = zb_zcl_set_attr_val(
		SOURCE_ENDPOINT,								// 1
		ZB_ZCL_CLUSTER_ID_REL_HUMIDITY_MEASUREMENT,		// 0x0405
		ZB_ZCL_CLUSTER_SERVER_ROLE,						// 1
		ZB_ZCL_ATTR_REL_HUMIDITY_MEASUREMENT_VALUE_ID,
		(zb_uint8_t *)&humidity_attribute,
		ZB_FALSE
	);

	if (status) {
		LOG_ERR("Failed to set ZCL attribute: %d", status);
	} else{
		LOG_INF("Humidity attribute update: %.2f%%", measured_humidity);
	}

	if(ZB_JOINED()){
		zb_ret_t zb_err = ZB_SCHEDULE_APP_ALARM(
			check_temp_humidity, 0,
			ZB_MILLISECONDS_TO_BEACON_INTERVAL(TEMP_HUMIDITY_CHECK_PERIOD_MSEC));
		if (zb_err) LOG_ERR("Failed to schedule temperature & humidity check alarm: %d", zb_err);
		else LOG_INF("Scheduled next temperature & humidity check alarm in %ds", TEMP_HUMIDITY_CHECK_PERIOD_MSEC/1000);
	}

	// Trigger Single-Shot
	// 0xC210 = Auto Range, 100ms
	// 0xCA10 = Auto Range, 800ms
	opt3001_write_mode(opt30, 0xCA10);
	k_sleep(K_MSEC(850));
	sensor_sample_fetch(opt30);

	uint16_t illuminance_attribute = 0;

	struct sensor_value illum;
	sensor_channel_get(opt30, SENSOR_CHAN_LIGHT, &illum);
	measured_illuminance = sensor_value_to_double(&illum);
	
	// Convert measured value to attribute value, as specified in ZCL
	if (measured_illuminance > 1.0){
		double val_calc = 10000.0 * log10(measured_illuminance) + 1.0;
		if (val_calc > 0xFFFE) {
            illuminance_attribute = 0xFFFE;
        } else {
            illuminance_attribute = (uint16_t)val_calc;
        }
	}
	else {
		illuminance_attribute = 0x0000;
	}
	//LOG_INF("Attribute I:%d", illuminance_attribute);
	
	// Set ZCL attribute
	status = zb_zcl_set_attr_val(
		SOURCE_ENDPOINT,										// 1
		ZB_ZCL_CLUSTER_ID_ILLUMINANCE_MEASUREMENT,				// 0x0402
		ZB_ZCL_CLUSTER_SERVER_ROLE,								// 1
		ZB_ZCL_ATTR_ILLUMINANCE_MEASUREMENT_MEASURED_VALUE_ID,	// 0
		(zb_uint8_t *)&illuminance_attribute,
		ZB_FALSE
	);

	if (status) {
		LOG_ERR("Failed to set ZCL attribute: %d", status);
	} else{
		LOG_INF("Illuminance attribute update: %d", illuminance_attribute);
	}

}

//---------------------------------------------------------------------------------------------
// use the adc to periodically read the battery voltage on vdd pin and update the 
// battery voltage attribute. if joined to a network, send the attribute report.
// using the old nrfx saadc driver because it permits the adc to be shutdown between
// samples. the zephyr saadc driver does not have this capability.
//

#define NRFX_SAADC_CONFIG_IRQ_PRIORITY 6

// Battery level update routine
static void check_battery_level(zb_bufid_t bufid){

	nrfx_err_t status;
	nrfx_saadc_channel_t channel;
	uint16_t sample;

	// initialize adc
	status = nrfx_saadc_init (NRFX_SAADC_CONFIG_IRQ_PRIORITY);

	channel.channel_config.resistor_p = NRF_SAADC_RESISTOR_DISABLED;
	channel.channel_config.resistor_n = NRF_SAADC_RESISTOR_DISABLED;
	channel.channel_config.gain       = NRF_SAADC_GAIN1_6;
	channel.channel_config.reference  = NRF_SAADC_REFERENCE_INTERNAL;
	channel.channel_config.acq_time   = NRFX_SAADC_DEFAULT_ACQTIME;
	channel.channel_config.mode       = NRF_SAADC_MODE_SINGLE_ENDED;
	channel.channel_config.burst      = NRF_SAADC_BURST_DISABLED;
	channel.pin_p                     = NRF_SAADC_INPUT_AIN7; // AIN7 = P0.31
	channel.pin_n                     = NRF_SAADC_INPUT_DISABLED;
	channel.channel_index             = 0;

    status = nrfx_saadc_channel_config (&channel);

	status = nrfx_saadc_simple_mode_set ((1<<0),
                                         NRF_SAADC_RESOLUTION_14BIT,
                                         NRF_SAADC_OVERSAMPLE_8X,
                                         NULL);
        
    status = nrfx_saadc_buffer_set (&sample, 1);

	// read sample
    status = nrfx_saadc_mode_trigger ();

	// shutdown adc to save power
	nrfx_saadc_uninit ();

	// convert to millivolts
	int32_t resolution = 14;
	int32_t gainrecip = 6;
	int32_t ref_mv = 600;
	int32_t adc_mv = (sample * ref_mv * gainrecip) >> resolution;

	// convert to percentage remaining
	zb_uint8_t battery_level = NiMH_CalculateLevel(adc_mv);
	//LOG_INF ("adc: %04x / %d mV / %d", sample, adc_mv, battery_level);

	zb_uint8_t percentage_attribute = battery_level * 2;
	// update percentage remaining attribute value
    zb_zcl_status_t stat = zb_zcl_set_attr_val (SOURCE_ENDPOINT,
                         ZB_ZCL_CLUSTER_ID_POWER_CONFIG, 
                         ZB_ZCL_CLUSTER_SERVER_ROLE, 
                         ZB_ZCL_ATTR_POWER_CONFIG_BATTERY_PERCENTAGE_REMAINING_ID,
                         &percentage_attribute, 
                         ZB_FALSE);
	if (stat) {
		LOG_ERR("Failed to set battery attribute: %d", stat);
	} else{
		LOG_INF("battery attribute update: %d mV / %d%%", adc_mv, battery_level);
	}

	//Schedule next alarm
	if(ZB_JOINED()){
		zb_ret_t zb_err = ZB_SCHEDULE_APP_ALARM(
			check_battery_level, 0,
			ZB_MILLISECONDS_TO_BEACON_INTERVAL(BATTERY_CHECK_PERIOD_MSEC));
		if (zb_err) LOG_ERR("Failed to schedule battery check alarm: %d", zb_err);
		else LOG_INF("Scheduled next battery check alarm in %ds", BATTERY_CHECK_PERIOD_MSEC/1000);
	}
}

//---------------------------------------------------------------------------------------------
// zigbee stack event handler
//
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

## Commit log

2025-11-16 Fix image filename case in README.md
2025-12-29 Added OPT3001 sensor
    [Zicada.kicad_pcb, Zicada.kicad_sch]
2025-12-31 generated fabrication files
    [Zicada.kicad_pcb, Zicada.kicad_sch, bom.csv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]
2026-02-08 V2 CAD files added
    These optional files include holes for improved airflow in the from case as well as a larger button needed for light sensing
    [ButtonV2.stl, FrontV2.stl, Zicada Rev2.step]
2026-02-08 Added OPT3001 to the firmware and converter
    - OPT3001 now included in the board config
    - illuminance clutser added to the zigbee config
    - z2m converter file updated
2026-07-19 PCB: Fehler behoben
    - Verpolung OP Versorgung korrigiert
    - Ideale Dioden nur noch passiv, da Ansteuerung Quatsch wg. Bodydiode
    - Enable I2C-Treiber auf VDDA
2026-07-19 Revert "PCB: Fehler behoben"
    This reverts commit e2776d45b51652c98892919577f71c7c98e397fe.
